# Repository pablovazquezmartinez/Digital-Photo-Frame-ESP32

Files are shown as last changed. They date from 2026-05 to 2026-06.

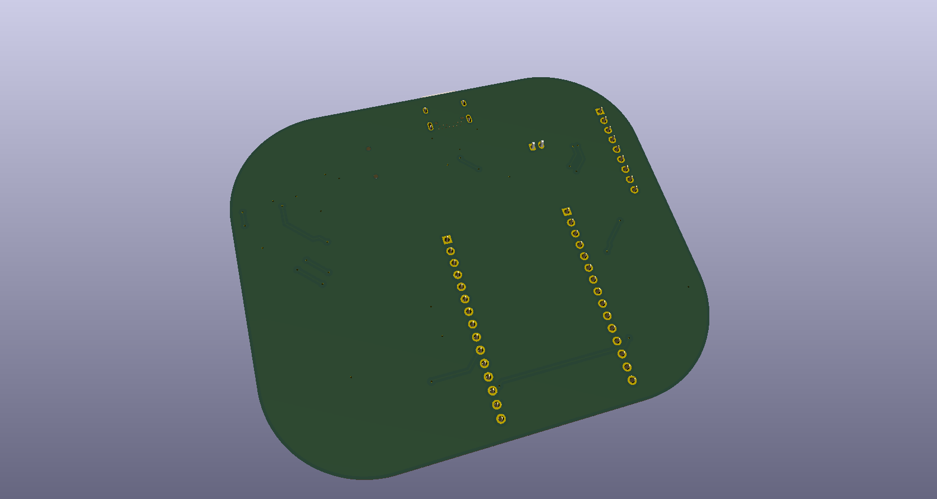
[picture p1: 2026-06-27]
photos/photo7_PCB_back.png

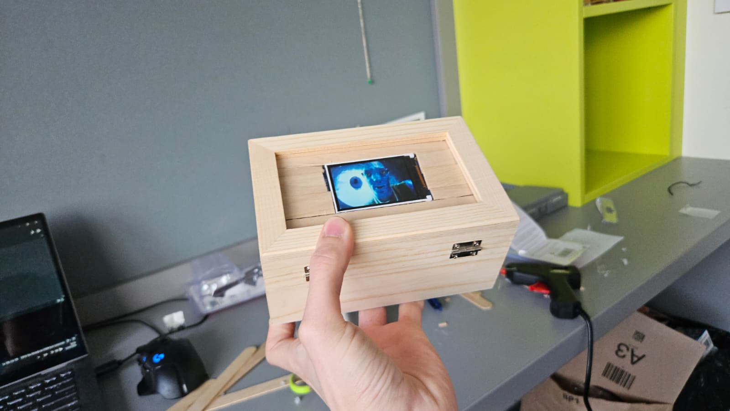
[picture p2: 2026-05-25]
photos/photo5.jpeg

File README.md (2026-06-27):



# ESP32 Digital Photo Frame

A DIY digital photo frame project using an **ESP32** and an **ILI9341 TFT display**. This project features a dual SPI bus configuration to eliminate data interference and maximize image loading speeds. The repository also includes a custom PCB design, including all KiCad source and fabrication files. The board is production-ready and plug-and-play.

## Key Features
* **Dual SPI Architecture:** Uses separate buses for the Display (VSPI) and the SD Card (HSPI) for stable, high-speed performance.
* **Buffer-Optimized Rendering:** Fast BMP processing using memory buffering.
* **Random Start:** Picks a completely random image from the SD card every time it boots up.
* **Auto-Slideshow (Default):** Advances to the next image every 5 seconds automatically.
* **Manual Control:** Dedicated buttons for "Next" and "Previous" navigation.
* **Dynamic Mode Toggle:** Switch between Manual and Auto modes by holding both buttons for 3 seconds.

## Hardware Requirements
* ESP32 DevKit V1
* ILI9341 TFT Display (2.8" or 2.4" SPI)
* Micro SD Card Module
* 2x Push Buttons
* Lithium Battery, Charger Module (TP4056) and toggle button (Optional)

## Wiring & Pinout
To avoid boot loops and "strapping pin" conflicts, the following pinout is used. 

> [!IMPORTANT]
> The display used for the proyect do not have a CS pin.
> All GND have to be connected to the same GND ESP32 pin.
> VERY CAREFULL with the polarity of the battery, charger pins and conexions with ESP32.
> Refer to the **Schematics.pdf** file in this repository for the full visual circuit diagram.

| Component | Pin Name | ESP32 Pin | SPI Bus |
| :--- | :--- | :--- | :--- |
| **Display** | VCC | 3v3 | - |
| | CLK | GPIO 18 | VSPI |
| | MOSI | GPIO 23 | VSPI |
| | RES | GPIO 4 | - |
| | DC | GPIO 2 | - |
| | BLK | 3v3 | - |
| | MISO | GPIO 19 | - |
| | GND | GND | - |
| **SD Card** | CS | GPIO 33 | HSPI |
| | MOSI | GPIO 25 | HSPI |
| | CLK | GPIO 22 | HSPI |
| | MISO | GPIO 32 | HSPI |
| | 3V3 | 3v3 | - |
| | GND | GND | - |
| **Buttons** | Next | GPIO 27 | - |
| | Prev | GPIO 26 | - |
| | GND | GND | - |
| **Charger** | Out+ | VIN | - |
| | Out- | GND | - |

| Component | Pin Name | Charger Pin |
| :--- | :--- | :--- |
| **Battery** | RED | B+ |
| | BLACK | B- |

## Image Preparation
To ensure the frame works correctly, your images must be formatted as follows:
* **Format:** BMP (Windows 24-bit / R8 G8 B8).
* **Resolution:** 320x240 pixels.
* **Storage:** Place images in the root directory of a FAT32 formatted Micro SD card.
### Automated Image Batch Converter (Python Script)
To save time, an automated Python utility is provided in the `tools/` directory to process images in bulk. 

The script prompts you for the full path of your source image folder. It then automatically scales, converts, and exports all compatible files into a newly created `Images-ready-to-use/` directory.

>  **Important:** The ESP32 firmware expects images to be in the root directory of the SD card. When moving the processed files, copy the **contents** of the `Images-ready-to-use` folder directly into the SD card, rather than copying the folder itself.

#### Prerequisites
Before running the script, you need to have **Python 3** installed on your computer and install the required image libraries.

1. **Install Python 3:** Ensure Python is installed and added to your system's PATH.
2. **Install Libraries:** Open your computer's terminal (Command Prompt, PowerShell, or Terminal) and run the following command to install the required dependencies:

```bash
pip install pillow pillow_heif
```

## User Controls
* **Manual Navigation:** Press the "Next" (GPIO 27) or "Previous" (GPIO 26) button.
* **Mode Switch:** Press and hold **both buttons simultaneously for 3 seconds**. 
    * **Green Label:** Auto-mode active.
    * **Red Label:** Manual mode active.
* **On-off control:** Press the toggle button conected to the battery.

## PCB Design (Hardware)

This project includes the complete design of a production-ready custom carrier board. It is designed to be fully *plug-and-play*: you simply need to plug the ESP32 and the display into their respective sockets, with no manual soldering required.

### Display Compatibility (Extra CS Pin)

The original design of this PCB is optimized for standard 8-pin displays. However, to maximize the project's compatibility, **I have added an extra pin** for displays that include a **CS (Chip Select)** pin. 

At the hardware level, this additional control pin is physically routed to **GPIO 15** on the ESP32.

**Firmware Configuration:**

If you are using an 8-pin display, you don't need to do anything (it works out of the box). But if your display requires the use of the CS pin, you must enable it in the software by following this simple step:

Go to the main code file (`main`) and locate **line 10**. You will need to change the disabled value (`-1`) to the corresponding pin (`15`).

```cpp
// ❌ Default configuration (8-pin displays without CS):
#define TFT_CS -1

// ✅ Modified configuration (Displays with CS pin connected):
#define TFT_CS 15
```
photo6_PCB_front

## Getting Started
1.  Clone this repository.
2.  Install `Adafruit_ILI9341` and `Adafruit_GFX` libraries in your Arduino IDE.
3.  Upload the `main.ino` sketch to your ESP32.
4.  Check the **Schematics.pdf** for wiring details.

---
*Code helped by AI*
*Created by Pablo Vazquez*

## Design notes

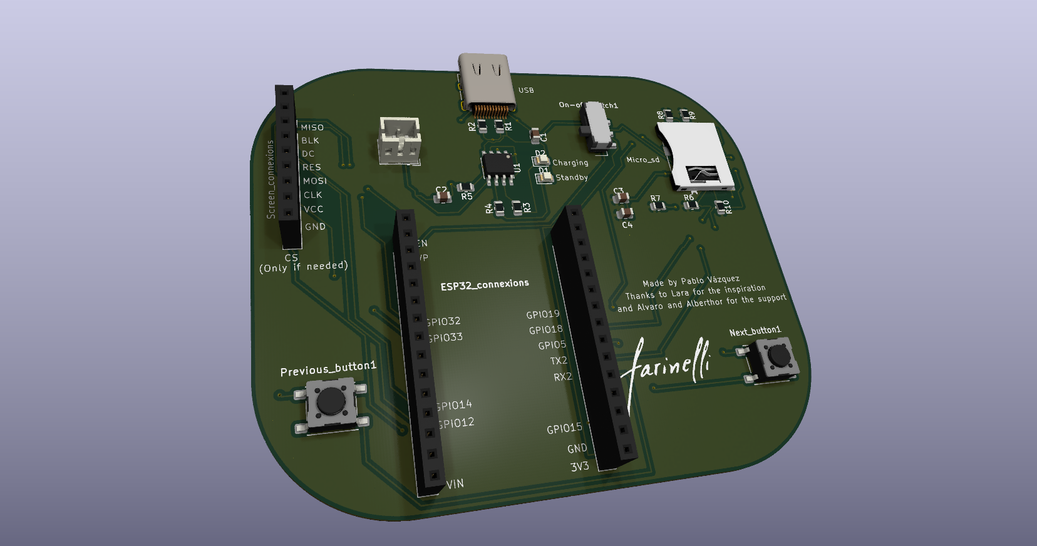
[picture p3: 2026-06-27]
photos/photo6_PCB_front.png

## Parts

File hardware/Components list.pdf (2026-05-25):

This is the complete list of the components I used for the project and the link to buy them:

- ESP32:
https://www.amazon.ie/dp/B071JR9WS9?ref=ppx_yo2ov_dt_b_fed_asin_title
- TFT ILI9341 Screen:
https://www.amazon.ie/dp/B07QFVBLDS?ref=ppx_yo2ov_dt_b_fed_asin_title
- Micro SD and card reader module: https://www.amazon.ie/dp/B0DRWPJ1T5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
- Charger Module:
https://www.amazon.ie/dp/B0FD9GXYR1?ref=ppx_yo2ov_dt_b_fed_asin_title
- Battery:
https://www.amazon.ie/dp/B095VQRW73?ref=ppx_yo2ov_dt_b_fed_asin_title&th=1

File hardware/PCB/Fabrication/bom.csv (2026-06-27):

Designator | Footprint | Quantity | Value | LCSC Part #
C1, C2, C3 | 0805 | 3 | 10μF
C4 | 0805 | 1 | 100nF
D1 | 0805 | 1 | LED_GREEN_0805
D2 | 0805 | 1 | LED_RED_0805
J1 | USB_C_Receptacle_XKB_U262-16XN-4BVC11 | 1 | USB_C_Receptacle_USB2.0_14P
J2, J4 | PinSocket_1x15_P2.54mm_Vertical | 2 | Conn_01x15_Socket
J3 | JST_PH_B2B-PH-K_1x02_P2.00mm_Vertical | 1 | Conn_01x02_Pin
J5 | microSD_HC_Molex_104031-0811 | 1 | Micro_SD_Card
J6 | PinSocket_1x09_P2.54mm_Vertical | 1 | Conn_01x08_Socket
NEXT_BUTTON1, PREVIOUS_BUTTON1 | SW_SPST_PTS645Sx43SMTR92 | 2 | SW_Push
ON-OFF_SWITCH1 | SW_SPDT_CK_JS102011SAQN | 1 | SW_SPDT
R1, R2 | 0805 | 2 | 5,1kΩ
R10, R6, R7, R8, R9 | 0805 | 5 | 10kΩ
R3, R4 | 0805 | 2 | 1kΩ
R5 | 0805 | 1 | 1,2kΩ
U1 | SOIC-8-1EP_3.9x4.9mm_P1.27mm_EP2.29x3mm | 1 | TP4056-42-ESOP8

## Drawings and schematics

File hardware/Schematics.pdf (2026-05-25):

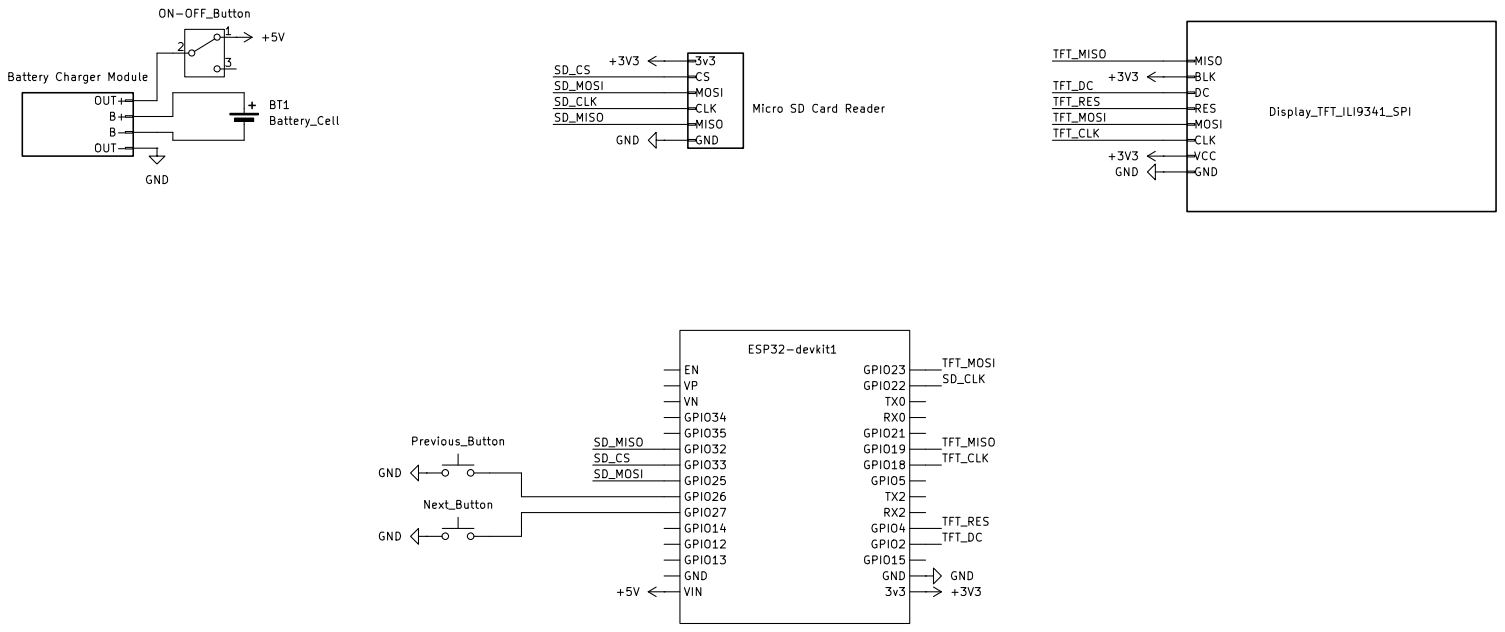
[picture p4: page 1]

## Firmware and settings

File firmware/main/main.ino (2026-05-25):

#include <SPI.h>
#include <SD.h>
#include <Adafruit_GFX.h>
#include <Adafruit_ILI9341.h>
#include <vector>

// --- CONFIGURACIÓN DE PINES ---
#define TFT_DC   2
#define TFT_RST  4
#define TFT_CS  -1 
Adafruit_ILI9341 tft(TFT_CS, TFT_DC, TFT_RST);

#define SD_CS   33
#define SD_MOSI 25
#define SD_SCK  22
#define SD_MISO 32
SPIClass hspi(HSPI);

#define BTN_NEXT 27
#define BTN_PREV 26

// --- VARIABLES DE CONTROL ---
std::vector<String> fileList;
int currentFileIndex = 0;
#define BUFFPIXEL 60 

bool autoMode = true; // Empieza en modo automático por defecto
unsigned long lastAutoAdvance = 0;
unsigned long buttonsPressedStart = 0;
const unsigned long AUTO_INTERVAL = 5000; // 5 segundos
const unsigned long MODE_SWITCH_TIME = 3000; // 3 segundos pulsando ambos

void setup() {
  Serial.begin(115200);

  // Generar una semilla aleatoria usando un pin analógico vacío
  randomSeed(analogRead(34)); 

  pinMode(BTN_NEXT, INPUT_PULLUP);
  pinMode(BTN_PREV, INPUT_PULLUP);

  tft.begin();
  tft.setRotation(1);
  tft.fillScreen(ILI9341_BLACK);
  tft.setTextColor(ILI9341_WHITE);
  tft.setTextSize(2);
  tft.println("Cargando Galeria...");

  hspi.begin(SD_SCK, SD_MISO, SD_MOSI, SD_CS);

  if (!SD.begin(SD_CS, hspi)) {
    tft.fillScreen(ILI9341_RED);
    tft.setCursor(10, 10);
    tft.println("ERROR: No hay SD");
    while (1);
  }

  loadFileList();
  
  if (fileList.size() > 0) {
    // Elegir una foto aleatoria para empezar
    currentFileIndex = random(0, fileList.size());
    showImage(currentFileIndex);
    Serial.print("Foto inicial aleatoria: ");
    Serial.println(fileList[currentFileIndex]);
  } else {
    tft.println("No hay .bmp en SD");
  }
}

void loop() {
  if (fileList.size() == 0) return;

  // 1. LÓGICA PARA CAMBIAR DE MODO (Pulsar ambos 3 segundos)
  if (digitalRead(BTN_NEXT) == LOW && digitalRead(BTN_PREV) == LOW) {
    if (buttonsPressedStart == 0) {
      buttonsPressedStart = millis();
    } else if (millis() - buttonsPressedStart >= MODE_SWITCH_TIME) {
      autoMode = !autoMode;
      mostrarFeedbackModo();
      buttonsPressedStart = 0;
      lastAutoAdvance = millis();
      delay(1000); 
    }
  } else {
    buttonsPressedStart = 0;
  }

  // 2. LÓGICA MODO AUTOMÁTICO
  if (autoMode) {
    if (millis() - lastAutoAdvance >= AUTO_INTERVAL) {
      currentFileIndex = (currentFileIndex + 1) % fileList.size();
      showImage(currentFileIndex);
    }
  } 
  
  // 3. LÓGICA MANUAL (Solo si un solo botón está presionado)
  else {
    if (digitalRead(BTN_NEXT) == LOW && digitalRead(BTN_PREV) == HIGH) {
      currentFileIndex = (currentFileIndex + 1) % fileList.size();
      showImage(currentFileIndex);
      delay(300);
    }
    if (digitalRead(BTN_PREV) == LOW && digitalRead(BTN_NEXT) == HIGH) {
      currentFileIndex--;
      if (currentFileIndex < 0) currentFileIndex = fileList.size() - 1;
      showImage(currentFileIndex);
      delay(300);
    }
  }
}

void mostrarFeedbackModo() {
  tft.fillRect(0, 0, 320, 35, ILI9341_BLACK);
  tft.setCursor(10, 10);
  if (autoMode) {
    tft.setTextColor(ILI9341_GREEN);
    tft.print("MODO: AUTOMATICO");
  } else {
    tft.setTextColor(ILI9341_RED);
    tft.print("MODO: MANUAL");
  }
  delay(1500);
  showImage(currentFileIndex); 
}

void showImage(int index) {
  drawBMP(fileList[index].c_str(), 0, 0);
  lastAutoAdvance = millis(); 
}

void loadFileList() {
  File root = SD.open("/");
  while (true) {
    File entry = root.openNextFile();
    if (!entry) break;
    String name = entry.name();
    if (name.endsWith(".bmp") || name.endsWith(".BMP")) {
      if (!name.startsWith("/")) name = "/" + name;
      fileList.push_back(name);
    }
    entry.close();
  }
  root.close();
}

void drawBMP(const char *filename, int x, int y) {
  File bmpFile = SD.open(filename);
  if (!bmpFile) return;
  if (read16(bmpFile) != 0x4D42) { bmpFile.close(); return; }
  read32(bmpFile); read32(bmpFile);
  uint32_t offset = read32(bmpFile);
  read32(bmpFile);
  int w = read32(bmpFile);
  int h = read32(bmpFile);
  uint32_t rowSize = (w * 3 + 3) & ~3;
  uint16_t *lcdbuffer = (uint16_t *)malloc(BUFFPIXEL * sizeof(uint16_t));
  uint8_t sdbuffer[3 * BUFFPIXEL];
  
  tft.startWrite();
  tft.setAddrWindow(x, y, w, h);
  for (int row = 0; row < h; row++) {
    bmpFile.seek(offset + (h - 1 - row) * rowSize);
    for (int col = 0; col < w; col += BUFFPIXEL) {
      int chunk = (col + BUFFPIXEL < w) ? BUFFPIXEL : (w - col);
      bmpFile.read(sdbuffer, 3 * chunk);
      for (int i = 0; i < chunk; i++) {
        uint8_t b = sdbuffer[i * 3], g = sdbuffer[i * 3 + 1], r = sdbuffer[i * 3 + 2];
        lcdbuffer[i] = tft.color565(r, g, b);
      }
      tft.writePixels(lcdbuffer, chunk);
    }
  }
  tft.endWrite();
  free(lcdbuffer);
  bmpFile.close();
}

uint16_t read16(File &f) { uint16_t result; f.read((uint8_t *)&result, sizeof(result)); return result; }
uint32_t read32(File &f) { uint32_t result; f.read((uint8_t *)&result, sizeof(result)); return result; }

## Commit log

2026-05-23 Update README with project details and instructions
    Added detailed project description, features, hardware requirements, wiring, image preparation, user controls, and getting started instructions.
2026-05-25 Update wiring details reference in README
2026-05-25 Update README for battery charger module details
2026-06-11 Added a automated Python tool
    I added a automated Python tool to convert the images to the correct format for the esp32 to display correctly.
2026-06-27 New custom PCB for the proyect
    Added custom PCB design, including all KiCad source and fabrication files. The board is production-ready and plug-and-play: you simply need to connect the ESP32 and the display, with no manual solder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
    [PCB_digitalscreen.kicad_pcb, PCB_digitalscreen.kicad_sch, bom.csv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]
2026-06-27 Added images of the custom PCB
2026-06-27 Enhance README with PCB design and production info
    Expanded project description to include PCB design details and production readiness.
2026-06-27 Enhance README with PCB design and display compatibility
    Updated project description and added PCB design section with compatibility details.
2026-06-27 Update README with image of the PCB
    Added an image of the PCB front to the README.
